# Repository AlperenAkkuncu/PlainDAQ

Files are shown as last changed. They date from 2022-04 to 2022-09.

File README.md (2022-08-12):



# PlainDAQ

PlainDAQ is a module that turns your Raspberry Pi Pico into a simple, precision 4-channel oscilloscope and a single channel function generator. Optionally it can also include a Wi-Fi module to add wireless capability to Raspberry Pi Pico modules.

To put it other words, PlainDAQ is a simple, useful tool to add basic precision analog functionality to your Raspberry Pi Pico board. It has a precision, low-noise, low-drift 12-bit 500kSPS/s ADC, sampling 4-channels and supporting 3 ranges (±1V, ±2V, ±4V). It also has a 10-bit DAC which helps create analog outputs and waveforms and it has a single range of ±4V.

Short List of features:

Analog Inputs:
• 4 Channels (multiplexed)  
• 12-bit resolution, 72dB SNR (11.6 ENOB,4000:1 dynamic range)  
• 500 kS/s sampling rate. 
• ±1V, ±2V, ±4V bipolar ranges.  

Analog Output:  
• 10-bit resolution.  
• 50 kS/s sampling rate.  
• ±4V bipolar range.  

Voltage Reference:
• 2.5V, 20ppm/°C (Typical) Drift  
• Calibrate to 0.05%, Stored in as ROM as calibration data. 

Bipolar Voltage Supply: 
• ±5V power output.   
• ±100mA current rating.    

ESP-WROOM-02D AT-Command Module:
• Simple UART interface to Raspberry Pico
• Wi-Fi connectivity    
• Shipped with ESP AT firmware 

# Here are some nice pictures of PlainDAQ
PlainDAQ_new_2
PlainDAQ_new_4

### Filter! More on that later
Filters

### The kit!
PlainDAQ_filters

## PlainDAQ Connections
plaindaq-board-layout-1

## PlainDAQ Components
plaindaq-board-layout-2

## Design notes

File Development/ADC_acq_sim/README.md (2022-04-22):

In PlainDAQ project I used PIO to interface with the ADC on board. 
"ADC_acq_sim" project simualted the ADC with PIO and acquires the data with PIO.

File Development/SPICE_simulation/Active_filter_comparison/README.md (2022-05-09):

Building a reconstruction filter for DAC output, so that I can generate nice looking sinewaves.
Here are the results:
The circuits I am comparing look like this:


The results are shown below:

As you can see MFB filter performs much better in the stop band

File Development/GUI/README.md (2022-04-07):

𝐒𝐭𝐫𝐞𝐬𝐬 𝐓𝐞𝐬𝐭
sinewave_stress_test

𝐂𝐮𝐫𝐬𝐨𝐫 𝐓𝐞𝐬𝐭

cursor_test

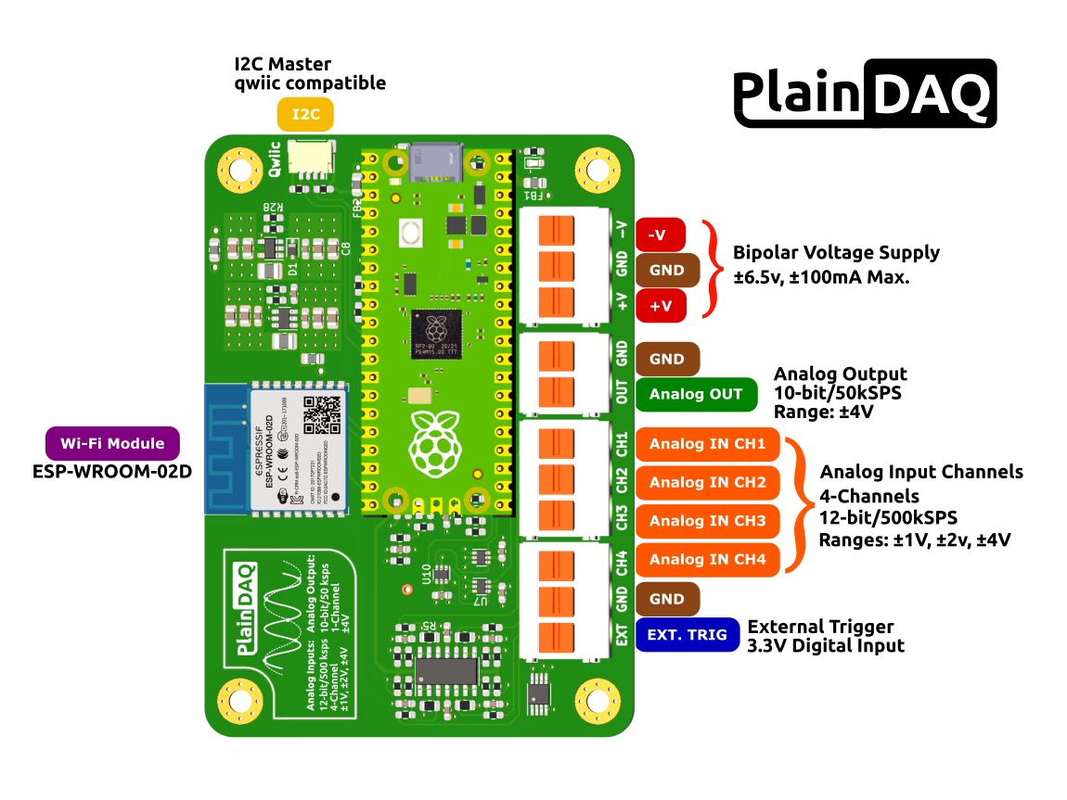
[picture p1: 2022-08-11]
pics/plaindaq-board-layout-1.png

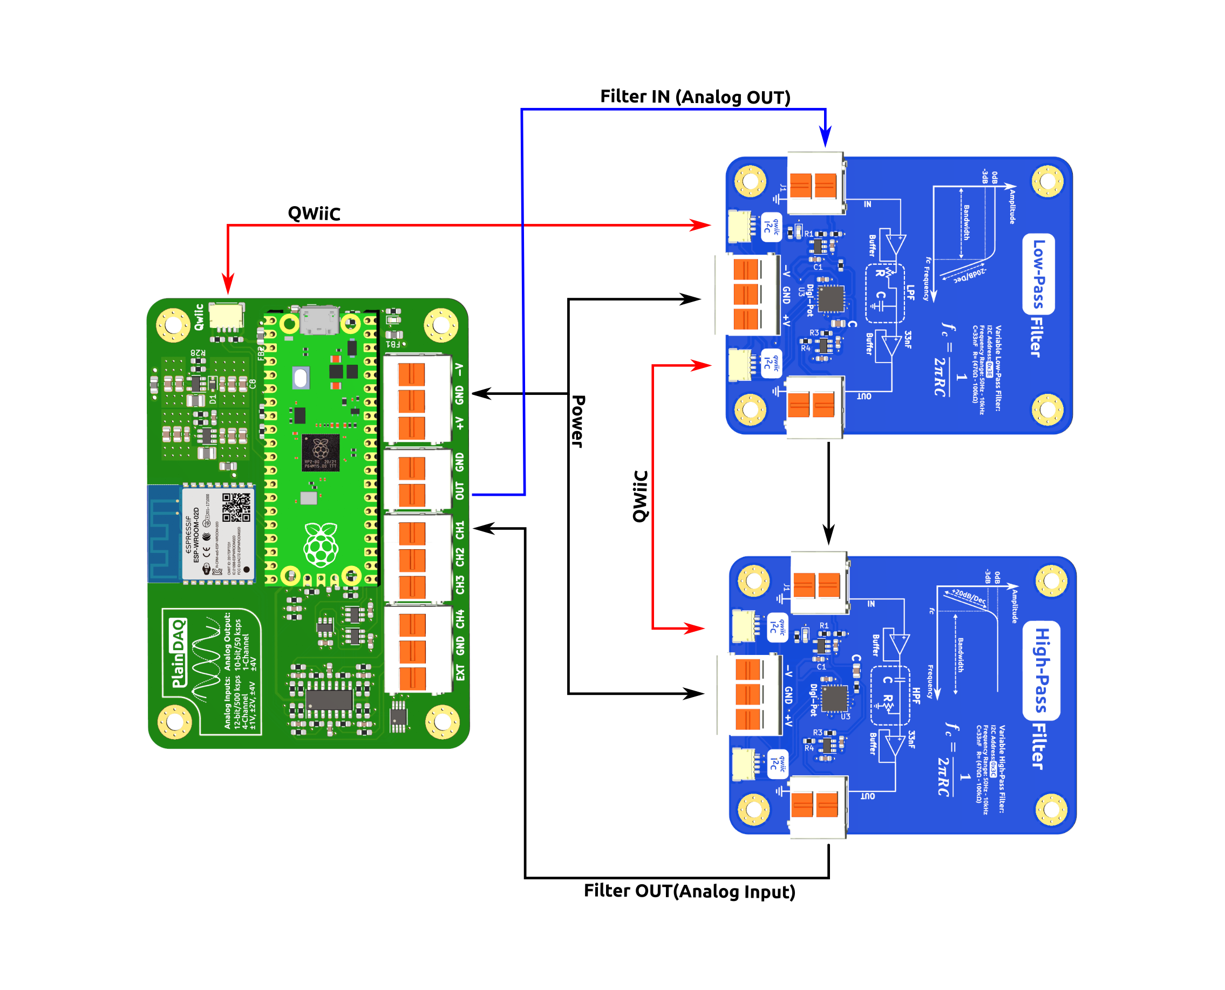
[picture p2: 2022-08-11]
pics/plaindaq-band-stop.png

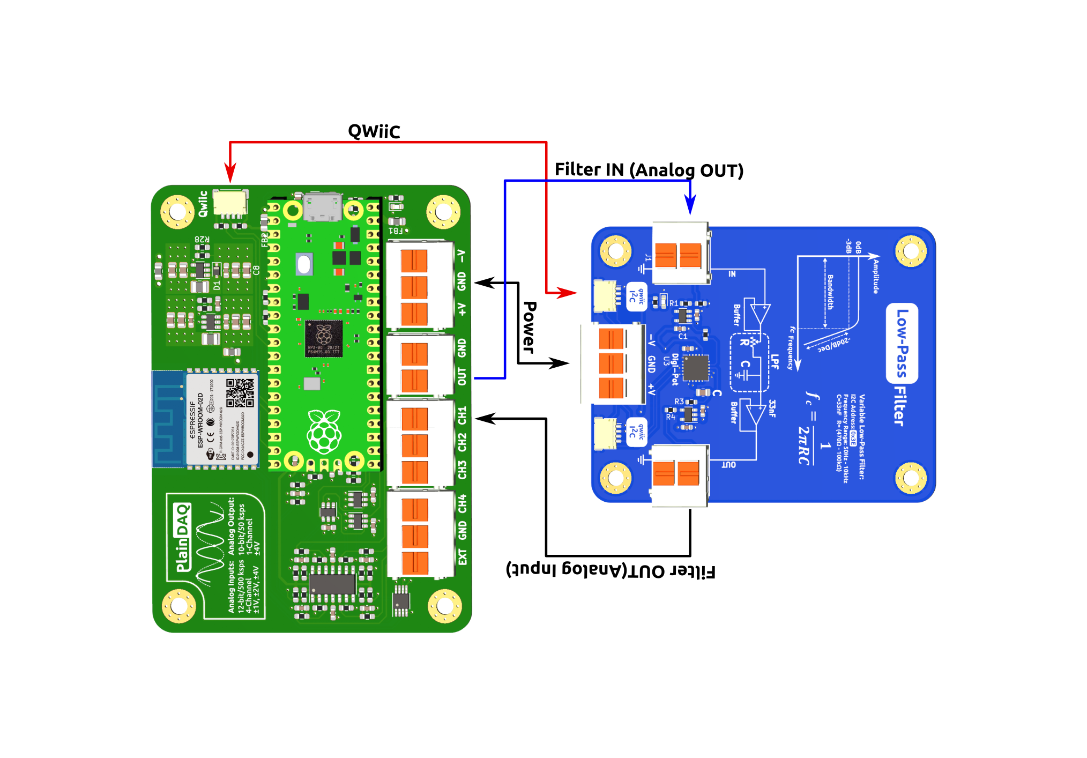
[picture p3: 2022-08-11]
pics/plaindaq-low-pass.png

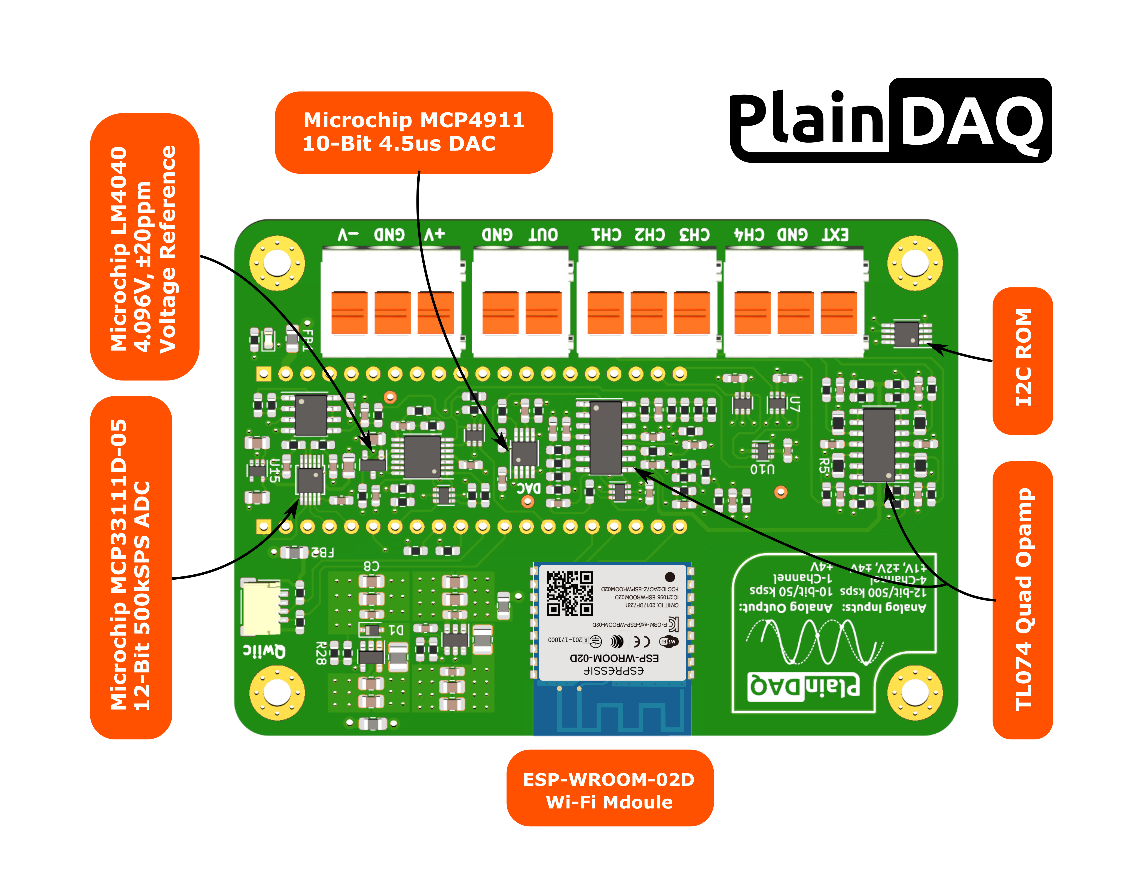
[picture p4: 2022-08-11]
pics/plaindaq-board-layout-2.png

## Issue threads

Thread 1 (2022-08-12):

Wi-Fi Module (to remove or not to remove)

AlperenAkkuncu, 2022-08-12:
Someone suggested me to remove the Wi-Fi module because one can buy a raspberry pico W and have the Wi-Fi capability, so there is no point having it in the board.

I've been thinking about removing it and adding a new feature.

What do you guys think?

avehbiaslanturk, 2022-08-12:
Yeah it might be good idea but first you should be sure that if it will be able to meet your needs in this project.

Derfboy, 2022-08-13:
Would definitely recommend removing it but also maybe having a fork that keeps it in for those of us who can't get our hands on the new Pico W.

Blaster1920, 2022-08-15:
I would remove it too.

Closed 2022-08-22.

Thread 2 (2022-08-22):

PlainDAQ new feature reccomendation.

AlperenAkkuncu, 2022-08-22:
Hello everyone,
I decided to remove the wi-fi module as Raspberry pico W is out and I am considering adding a new feature.

**What do you think I should add?**

These are some of the things I thought of adding:

- Storage (RAM, SDCard etc.)
- Variable power supply

What are your suggestions?

shanemmattner, 2022-08-24:
The [Espotek Labador](https://espotek.com/labrador/) seems to be doing similar functions as `PlainDAQ`, albeit with a simpler analog front end and no connectivity.  Take a look and see if there's anything worth stealing.

**Ideas/Comments**
- Use `ESP32` instead of `RPi Pico W`
  - Advantages:  Faster, FPU, lower sleep current, longer history in market, cheaper, smaller, professional quality chip, availability
- `SD card` is a good idea for longer term captures
- `Extra RAM` is probably useful, is it necessary yet?
- Couldn't the `DAC` act as a variable power supply?
- `Logic analyzer/generator`
- `Battery` circuit
- `Larger input range`
  - How high of voltage is practical (10v/20v/...)?
- `Circuit protection` like fuses and TVS diodes

AlperenAkkuncu, 2022-08-24:
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

Thank you for your contribution

I'll consider all of them, but I don't want to add too much functionality because I want to make something affordable and easy to manufacture. SDCard is definitely great as it's cheap to just add a connector, that's almost no brainer.

Extra RAM is quite good actually, but it's actually a bit expensive, but it might worth it.

It's kind of easy to add variable supply if things works according to my plan. I am planing to build a simple PWM DAC to create a variable supply, we'll see what I can do :)

I'll consider all of them for the future updates, thanks a lot.

Feedbacks like this motivates me.

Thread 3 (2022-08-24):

U3A -OUT supposed to connect to R14?

shanemmattner, 2022-08-24:
Should the `-OUT` be connected to R14 here?
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

AlperenAkkuncu, 2022-08-24:
Sorry for my late response @shanemmattner I am still getting used to github :)
Yes you are correct.
I will remove this schematic as it's not relevant right. I will upload the new version of the schematic files, once I launch the project on crowduspply.

In fact, I will share the whole KiCAD project :D

shanemmattner, 2022-08-24:
No problem, <24 hours response time on Github is lightning quick haha.

I look forward to seeing the full KiCAD project.  A brief explanation of the circuits (ie U2A and U3A) or links to documents you used to make the circuits would be great as well.

AlperenAkkuncu, 2022-08-24:
Thanks for the kind words :)
@shanemmattner are you asking the function of the FDA?

shanemmattner, 2022-08-24:
Yes, the FDA is a good example.  I didn't know the name of the circuit so I did not understand how it works.  I've created [this issue](https://github.com/AlperenAkkuncu/PlainDAQ/issues/4) for adding circuit theory documentation.  Let me know if I can help

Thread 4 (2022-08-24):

Add circuit theory documentation

shanemmattner, 2022-08-24:
It would be great to have a brief description of the circuits and perhaps some links to documentation explaining how the circuits work. I can help create the documents if you'd like

For example, in the picture below of U2A/U2B:

- `U2A` is a [voltage buffer](https://ultimateelectronicsbook.com/op-amp-voltage-buffer/)
- R5/R8 divide the input by 2
- `U2B` is a [summing differential amplifier](https://masteringelectronicsdesign.com/a-summing-and-differential-amplifier-with-one-op-amp/)
  - Is this correct?  Perhaps the equation for this circuit would be helpful
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

Then U3A circuits:
- `U3A` is a [fully-differential amplifier](https://www.ti.com/lit/an/sloa054e/sloa054e.pdf?ts=1661319105267)
- Output of `U3A` fed through [RC filters](https://www.electronics-tutorials.ws/filter/filter_2.html) (ie `R6`/`C4`, `R11`/`C7`) with cut-off freq ~`59Mhz`
  - Why 59Mhz?
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

AlperenAkkuncu, 2022-08-24:
> It would be great to have a brief description of the circuits and perhaps some links to documentation explaining how the circuits work. I can help create the documents if you'd like

That's a good idea. I was thinking about making videos, but I am not too sure how difficult it would be. Documenting stuff on github is a lot more efficient for me actually.

> * `U2A` is a [voltage buffer](https://ultimateelectronicsbook.com/op-amp-voltage-buffer/)
> * R5/R8 divide the input by 2

That's correct

> * `U2B` is a [summing differential amplifier](https://masteringelectronicsdesign.com/a-summing-and-differential-amplifier-with-one-op-amp/)

That's not correct, it's just a non-inverting opamp, if you follow the nets analog mux (U5) connects the resistor networks to achieve different gains.

> Output of `U3A` fed through [RC filters](https://www.electronics-tutorials.ws/filter/filter_2.html) (ie `R6`/`C4`, `R11`/`C7`) with cut-off freq ~`59Mhz`
> * Why 59Mhz?

It's kind of random, usually you need to use the lowest BW that you can work with to drive the ADC. Driving ADCs are quite difficult because it needs a lot of bandwidth. Determining exact values are quite difficult it's just requires quite a lot of trial and errors.

shanemmattner, 2022-08-25:
Making videos can be as involved as you'd like to make them.  I just uploaded some [new videos](https://youtube.com/playlist?list=PLkch9g9DEE0KpS7v0Ob3cLrQlZsCPJ6PP) on using SKiDL to make an ESP32 data logger (analog front end based on your project, thank you!).  You'll see they are pretty basic and just me talking over a screen.

AlperenAkkuncu, 2022-08-25:
> Making videos can be as involved as you'd like to make them. I just uploaded some [new videos](https://youtube.com/playlist?list=PLkch9g9DEE0KpS7v0Ob3cLrQlZsCPJ6PP) on using SKiDL to make an ESP32 data logger (analog front end based on your project, thank you!). You'll see they are pretty basic and just me talking over a screen.

Once I get an OK mic I can make it.
Great stuff by the way. :)

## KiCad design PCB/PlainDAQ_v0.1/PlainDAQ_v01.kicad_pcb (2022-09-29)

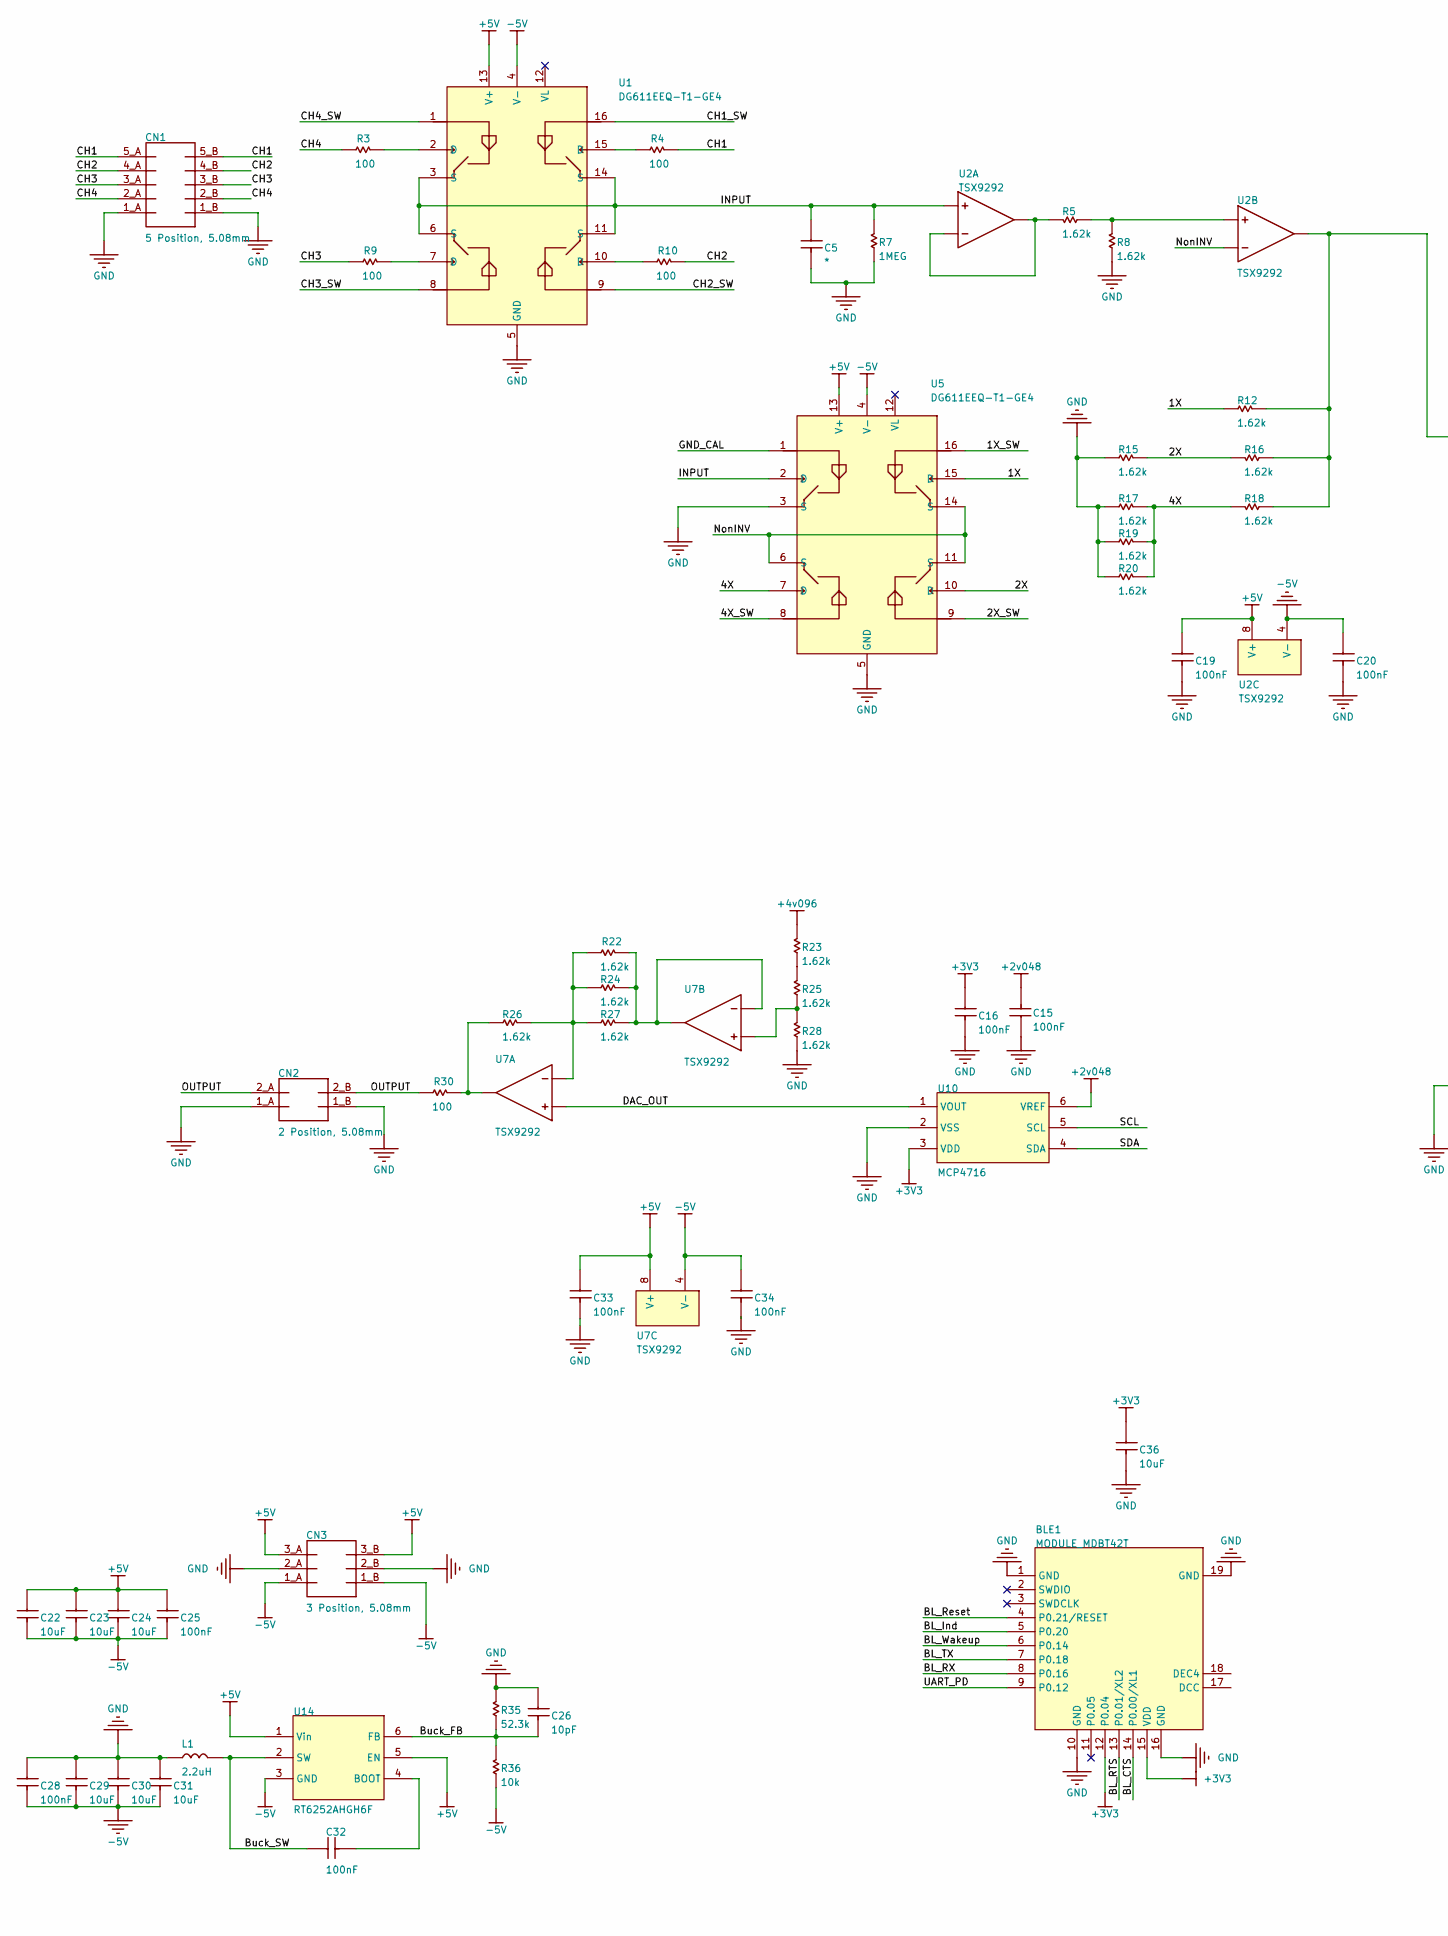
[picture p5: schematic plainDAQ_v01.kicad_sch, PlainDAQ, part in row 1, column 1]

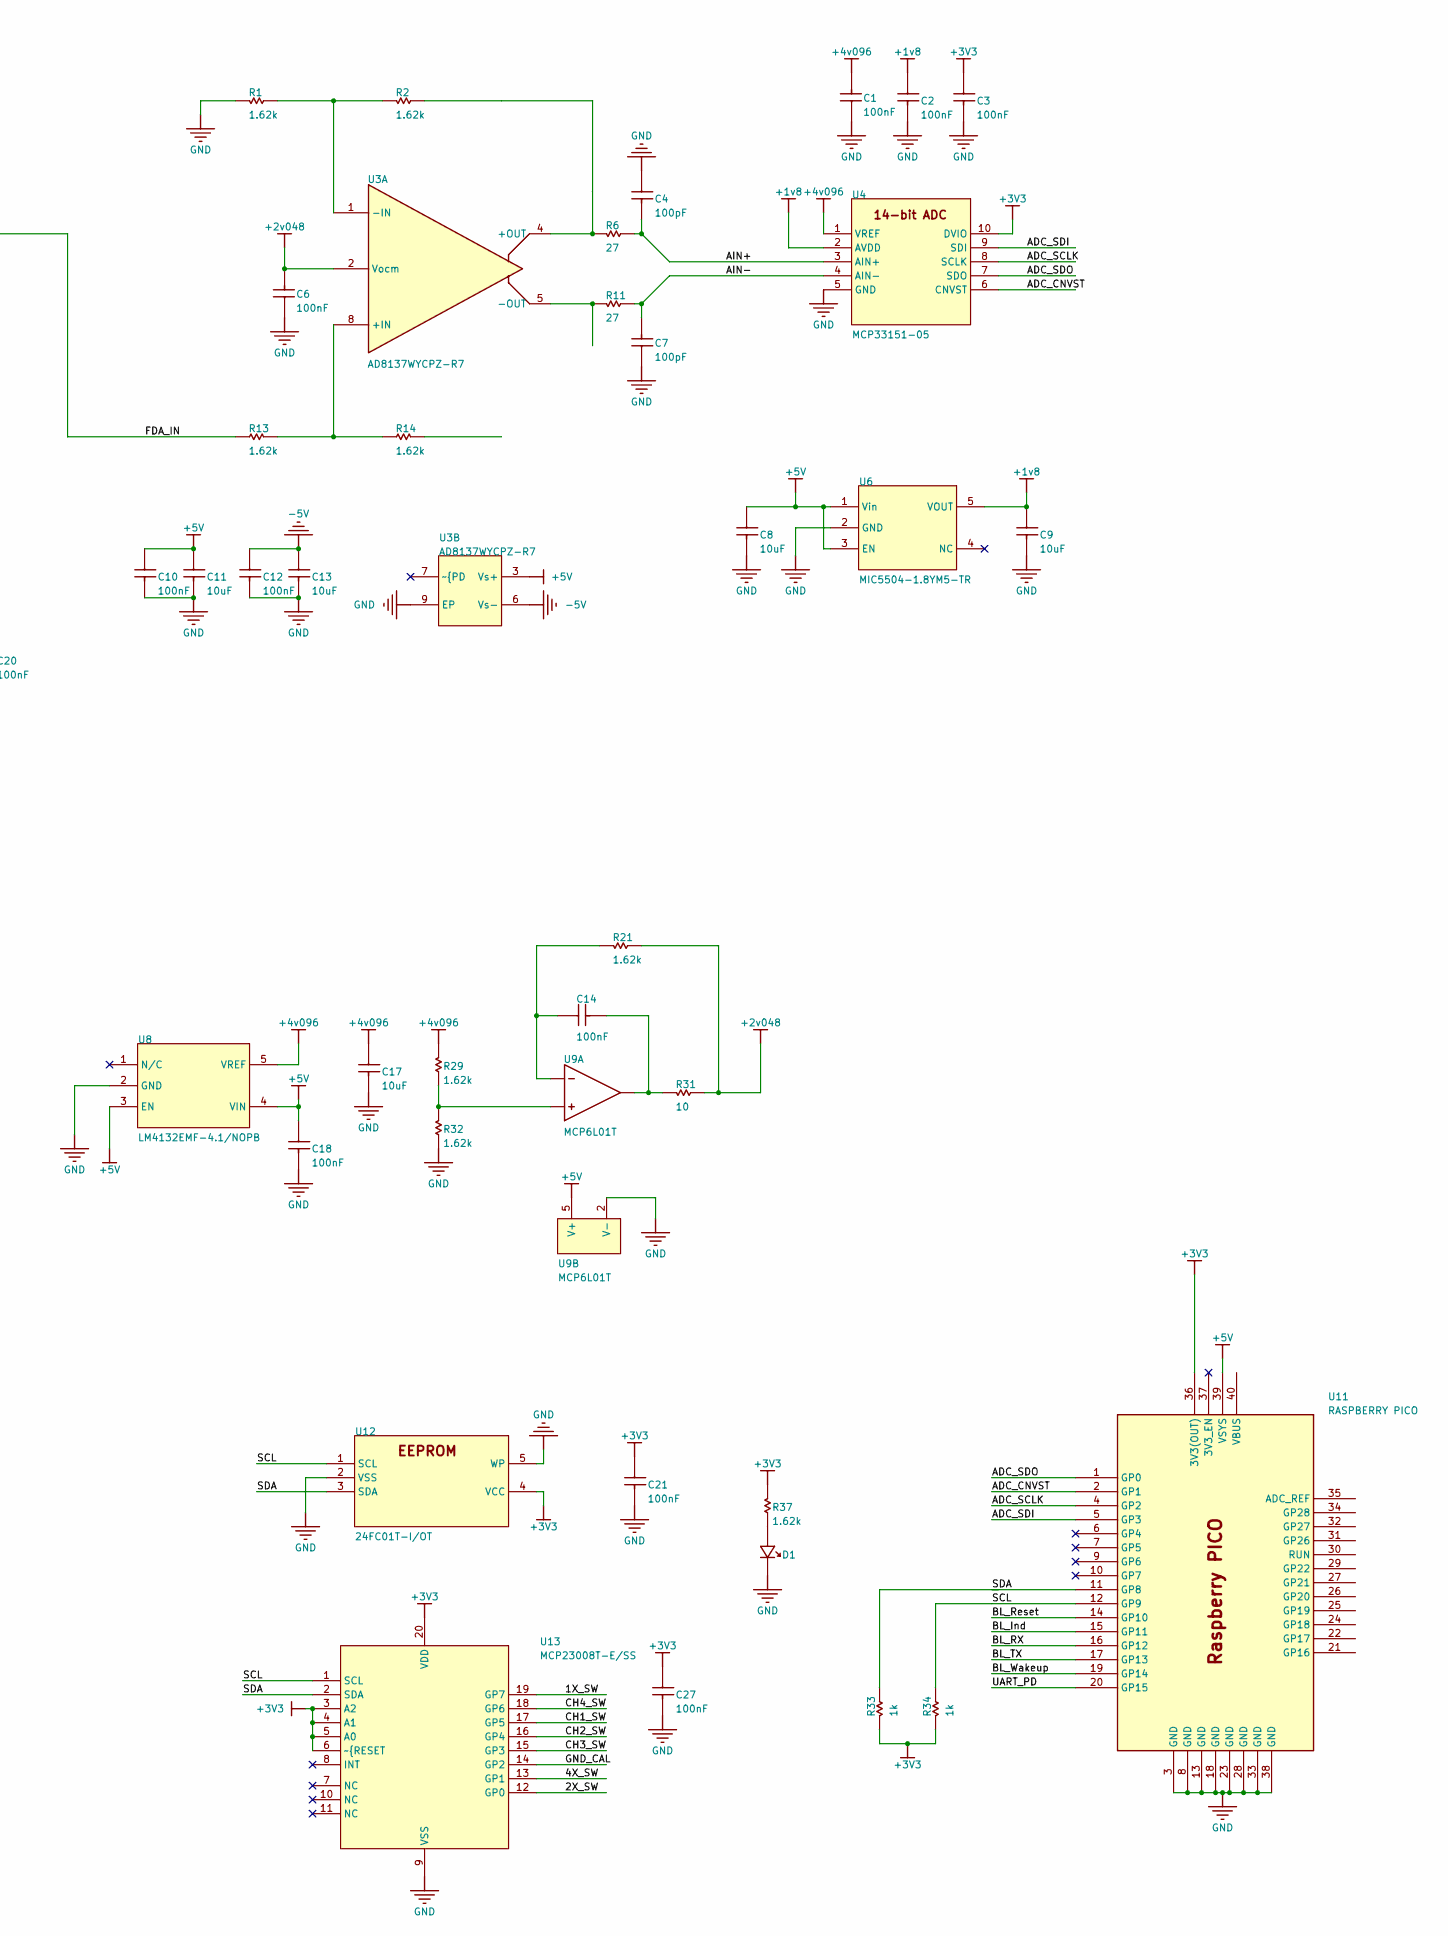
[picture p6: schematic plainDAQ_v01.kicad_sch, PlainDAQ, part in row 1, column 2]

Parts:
BLE1: MODULE_MDBT42T; PCB_MDBT42T_7.2X11.2
C1, C2, C3, C6, C10, C12, C14, C15, C16, C18, C19, C20, C21, C25, C27, C28, C32, C33, C34: 100nF; CAP-0603; TOLERANCE *
C4, C7: 100pF; CAP-0603; TOLERANCE *
C5: *; CAP-0603; TOLERANCE 10pF
C8, C9, C11, C13, C17, C22, C23, C24, C29, C30, C31, C36: 10uF; CAP-0805; TOLERANCE *
C26: 10pF; CAP-0603; TOLERANCE *
CN1: 5 Position, 5.08mm; CUI_TBL004-508-05BE-2GY; MANUFACTURER P/N TBL004V-508-05BE-2GY
CN2: 2 Position, 5.08mm; CUI_TBL004-508-02BE-2GY; MANUFACTURER P/N TBL004V-508-02BE-2GY
CN3: 3 Position, 5.08mm; CUI_TBL004-508-03BE-2GY; MANUFACTURER P/N TBL004V-508-03BE-2GY
D1: 150060SS75000; LED-0603
L1: 2.2uH; IND-0806
R1, R2, R5, R8, R12, R13, R14, R15, R16, R17, R18, R19, R20, R21, R22, R23, R24, R25, R26, R27, R28, R29, R32, R37: 1.62k; Res-0603; TOLERANCE *
R3, R4, R9, R10, R30: 100; Res-0603; TOLERANCE *
R6, R11: 27; Res-0603; TOLERANCE *
R7: 1MEG; Res-0603; TOLERANCE *
R31: 10; Res-0603; TOLERANCE *
R33, R34: 1k; Res-0603; TOLERANCE *
R35: 52.3k; Res-0603; TOLERANCE *
R36: 10k; Res-0603; TOLERANCE *
U1, U5: DG611EEQ-T1-GE4; TSOP65P640X110-16N
U2, U7: TSX9292; TSOP6-8 4x4 (NO PAD); MANUFACTURER P/N TSX9292IST
U3: AD8137WYCPZ-R7; SON-8 3.0X3.0, 2.00x1.49 PAD
U4: MCP33151-05; TSSOP50P490X110-10N; MANUFACTURER P/N MCP33151-05-E/MS
U6: MIC5504-1.8YM5-TR; SOT95P280X100-5N
U8: LM4132EMF-4.1/NOPB; SOT95P280X100-5N
U9: MCP6L01T; SOT65P210X110-5N; MANUFACTURER P/N MCP6L01T-E/LT
U10: MCP4716; SOT95P275X110-6N; MANUFACTURER P/N MCP4716A2T-E/CH
U11: RASPBERRY PICO; Raspberry_PICO
U12: 24FC01T-I/OT; SOT65P210X110-5N
U13: MCP23008T-E/SS; SOP65P780X200-20N
U14: RT6252AHGH6F; SOTFL50P160X60-6N

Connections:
1X: R12.2, U5.15 (D)
1X_SW: U5.16, U13.19 (GP7)
2X: R15.1, R16.1, U5.10 (D)
2X_SW: U5.9, U13.12 (GP0)
4X: R17.1, R18.1, R19.1, R20.1, U5.7 (D)
4X_SW: U5.8, U13.13 (GP1)
+1v8: C2.2, C9.2, U4.2 (AVDD), U6.5 (VOUT)
+2v048: C6.1, C15.1, R21.2, R31.2, U3.2 (Vocm), U10.6 (VREF)
+3V3: BLE1.12 (P0.04), BLE1.15 (VDD), C3.2, C16.2, C21.2, C27.2, C36.2, R33.2, R34.2, R37.1, U4.10 (DVIO), U10.3 (VDD), U11.36 (3V3(OUT)), U12.4 (VCC), U13.3 (A2), U13.4 (A1), U13.5 (A0), U13.6 (~{RESET), U13.20 (VDD); also elsewhere on the board
+4v096: C1.1, C17.2, R23.1, R29.1, U4.1 (VREF), U8.5 (VREF)
+5V: C8.2, C10.2, C11.2, C18.2, C19.2, C22.2, C23.2, C24.2, C25.2, C33.2, CN3.3_A, CN3.3_B, U1.13 (V+), U2.8 (V+), U3.3 (Vs+), U5.13 (V+), U6.1 (Vin), U6.3 (EN), U7.8 (V+), U8.3 (EN), U8.4 (VIN), U9.5 (V+), U11.39 (VSYS), U14.1 (Vin), U14.5 (EN)
-5V: C12.2, C13.2, C20.2, C22.1, C23.1, C24.1, C25.1, C28.1, C29.1, C30.1, C31.1, C34.2, CN3.1_A, CN3.1_B, R36.1, U1.4 (V-), U2.4 (V-), U3.6 (Vs-), U5.4 (V-), U7.4 (V-), U14.3 (GND)
ADC_CNVST: U4.6 (CNVST), U11.2 (GP1)
ADC_SCLK: U4.8 (SCLK), U11.4 (GP2)
ADC_SDI: U4.9 (SDI), U11.5 (GP3)
ADC_SDO: U4.7 (SDO), U11.1 (GP0)
AIN+: C4.1, R6.1, U4.3 (AIN+)
AIN-: C7.1, R11.1, U4.4 (AIN-)
BL_Ind: BLE1.5 (P0.20), U11.15 (GP11); also elsewhere on the board
BL_RX: BLE1.8 (P0.16), U11.16 (GP12); also elsewhere on the board
BL_Reset: BLE1.4 (P0.21/RESET), U11.14 (GP10); also elsewhere on the board
BL_TX: BLE1.7 (P0.18), U11.17 (GP13); also elsewhere on the board
BL_Wakeup: BLE1.6 (P0.14), U11.19 (GP14); also elsewhere on the board
Buck_FB: C26.1, R35.1, R36.2, U14.6 (FB)
Buck_SW: C32.2, L1.2, U14.2 (SW)
CH1: CN1.5_A, CN1.5_B, R4.1
CH1_SW: U1.16, U13.17 (GP5)
CH2: CN1.4_A, CN1.4_B, R10.1
CH2_SW: U1.9, U13.16 (GP4)
CH3: CN1.3_A, CN1.3_B, R9.2
CH3_SW: U1.8, U13.15 (GP3)
CH4: CN1.2_A (3), CN1.2_B, R3.2
CH4_SW: U1.1, U13.18 (GP6)
DAC_OUT: U7.3 (+INA), U10.1 (VOUT)
FDA_IN: R12.1, R13.2, R16.2, R18.2, U2.7 (OUTB)
GND: BLE1.1 (GND), BLE1.10 (GND), BLE1.16 (GND), BLE1.19 (GND), C1.2, C2.1, C3.1, C4.2, C5.1, C6.2, C7.2, C8.1, C9.1, C10.1, C11.1, C12.1, C13.1, C15.2, C16.1, C17.1, C18.1, C19.1, C20.1, C21.1, C26.2, C27.1, C28.2, C29.2, C30.2, C31.2, C33.1, C34.1, C36.1, CN1.1_A, CN1.1_B, CN2.1_A, CN2.1_B, CN3.2_A (3), CN3.2_B, D1.1, L1.1, R1.2, R7.2, R8.2, R15.2, R17.2, R19.2, R20.2, R28.2, R32.2, R35.2, U1.5 (GND), U3.9 (EP), U4.5 (GND), U5.3 (S), U5.5 (GND), U6.2 (GND), U8.2 (GND), U9.2 (V-), U10.2 (VSS), U11.3 (GND), U11.8 (GND), U11.13 (GND), U11.18 (GND), U11.23 (GND), U11.28 (GND), U11.33 (GND), U11.38 (GND), U12.2 (VSS), U12.5 (WP), U13.9 (VSS); also elsewhere on the board
GND_CAL: U5.1, U13.14 (GP2)
INPUT: C5.2, R7.1, U1.3 (S), U1.6 (S), U1.11 (S), U1.14 (S), U2.3 (+INA), U5.2 (D)
NetC14_1: C14.1, R31.1, U9.1 (OUT)
NetC14_2: C14.2, R21.1, U9.4 (-IN)
NetC32_1: C32.1, U14.4 (BOOT)
NetD1_2: D1.2, R37.2
NetR1_1: R1.1, R2.2, U3.1 (-IN)
NetR2_1: R2.1, R6.2, U3.4 (+OUT)
NetR3_1: R3.1, U1.2 (D)
NetR4_2: R4.2, U1.15 (D)
NetR5_1: R5.1, R8.1, U2.5 (+INB)
NetR5_2: R5.2, U2.1 (OUTA), U2.2 (-INA)
NetR9_1: R9.1, U1.7 (D)
NetR10_2: R10.2, U1.10 (D)
NetR13_1: R13.1, R14.2, U3.8 (+IN)
NetR22_1: R22.1, R24.1, R27.1, U7.6 (-INB), U7.7 (OUTB)
NetR22_2: R22.2, R24.2, R26.1, R27.2, U7.2 (-INA)
NetR23_2: R23.2, R25.1
NetR25_2: R25.2, R28.1, U7.5 (+INB)
NetR26_2: R26.2, R30.1, U7.1 (OUTA)
NetR29_2: R29.2, R32.1, U9.3 (+IN)
NonINV: U2.6 (-INB), U5.6 (S), U5.11 (S), U5.14 (S)
OUTPUT: CN2.2_A (3), CN2.2_B, R30.2
SCL: R34.1, U10.5 (SCL), U11.12 (GP9), U12.1 (SCL), U13.1 (SCL)
SDA: R33.1, U10.4 (SDA), U11.11 (GP8), U12.3 (SDA), U13.2 (SDA)
UART_PD: BLE1.9 (P0.12), U11.20 (GP15); also elsewhere on the board

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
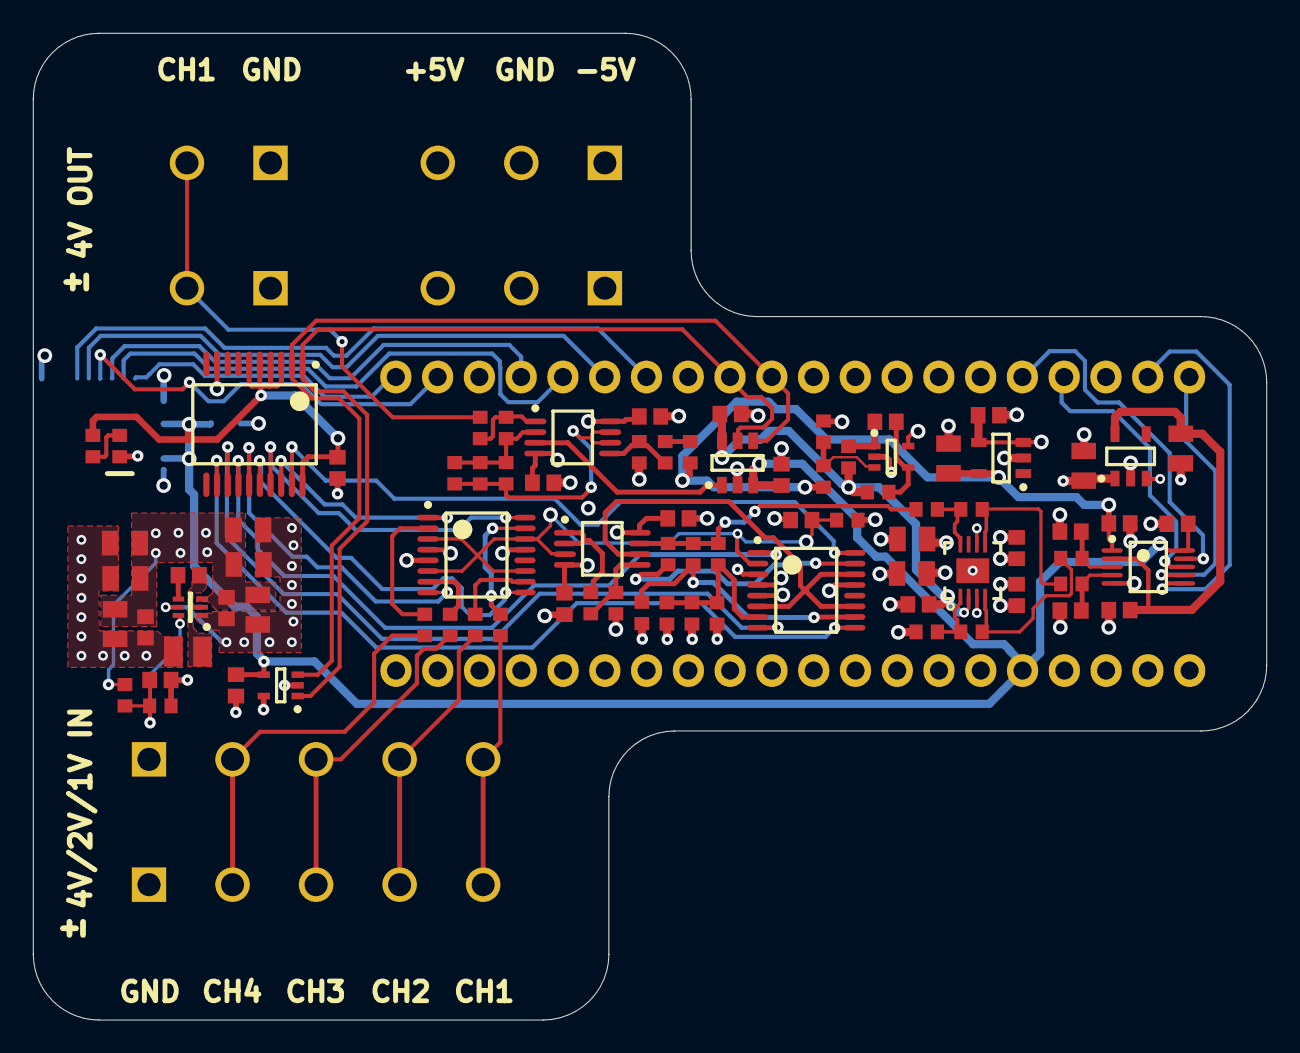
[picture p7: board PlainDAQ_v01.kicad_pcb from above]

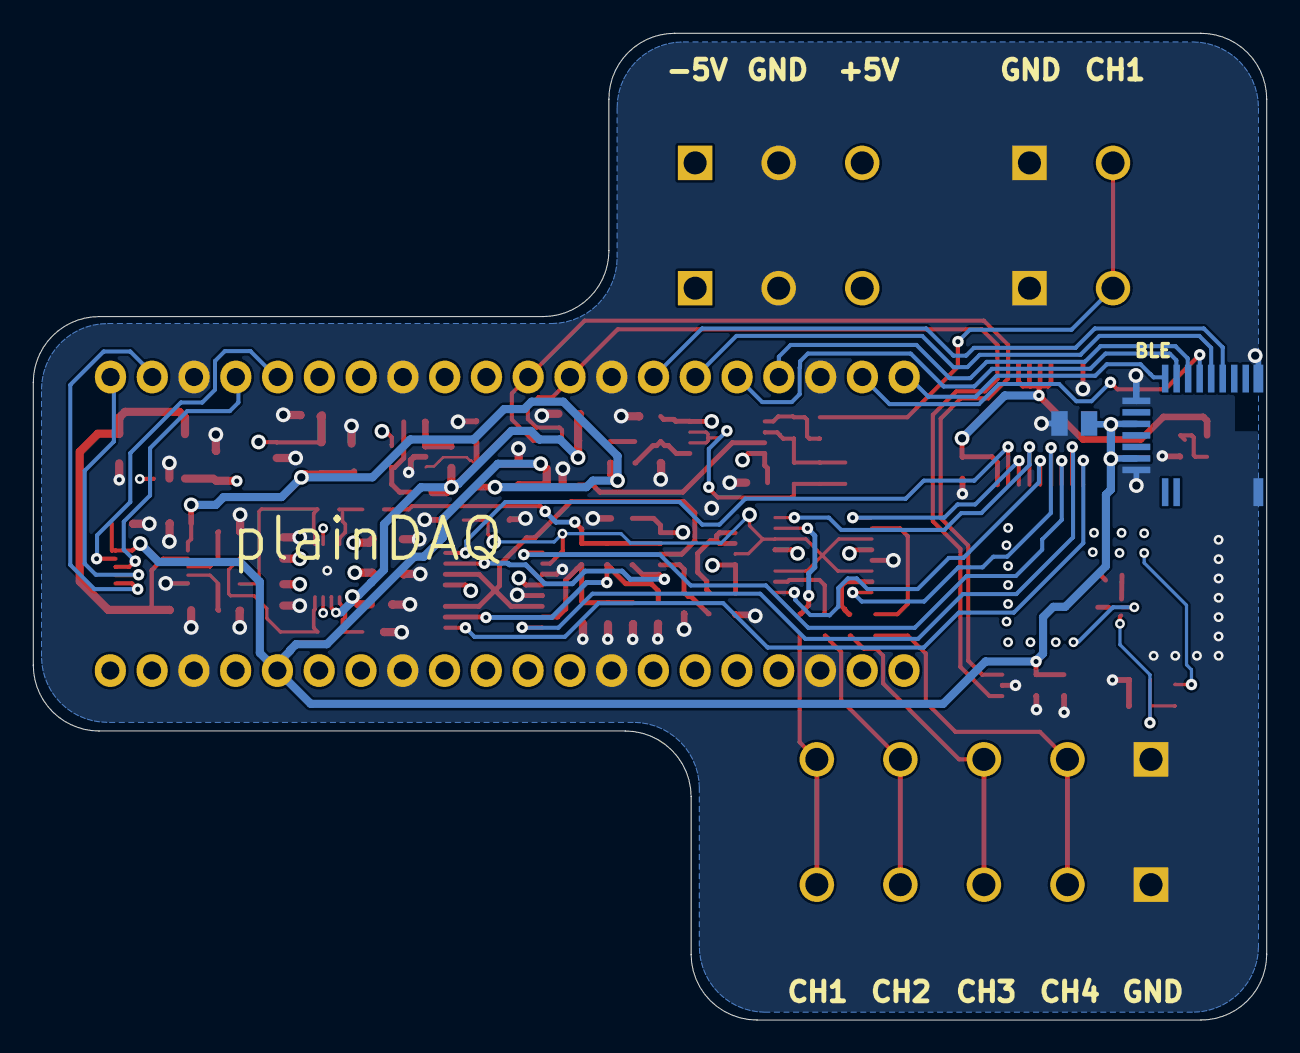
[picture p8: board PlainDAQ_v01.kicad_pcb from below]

Board: 4 copper layers, 75.0 x 60.0 mm, 90 parts (2 on the bottom side), 63 nets.

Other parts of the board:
BLE: MODULE_MDBT42T; PCB_MDBT42T_7.2X11.2

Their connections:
+3V3: BLE.12, BLE.15; also elsewhere on the board
BL_Ind: BLE.5; also elsewhere on the board
BL_RX: BLE.8; also elsewhere on the board
BL_Reset: BLE.4; also elsewhere on the board
BL_TX: BLE.7; also elsewhere on the board
BL_Wakeup: BLE.6; also elsewhere on the board
GND: BLE.1, BLE.10, BLE.16, BLE.19; also elsewhere on the board
UART_PD: BLE.9; also elsewhere on the board

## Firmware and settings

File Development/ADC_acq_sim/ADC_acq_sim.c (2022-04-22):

/**
 * Copyright (c) 2020 Raspberry Pi (Trading) Ltd.
 *
 * SPDX-License-Identifier: BSD-3-Clause
 */

// Output PWM signals on pins 0 and 1

#define ADC_SDO 0
#define ADC_CNVST 1
#define ADC_SCLK 2
#define ADC_SDI 3
#define ADC_SDO_SIM 4

#define CLK_GEN_SM 0
#define GET_SAMPLE_SM 1
#define GEN_DATA_SM 2

#define IO_EXPANDER_ADDR 0x27
#define IODIR 0x00
#define IOPOL 0x01
#define OLAT 0x0A

#define CLK_FREQ 125000000
#define PWM_FREQ 500000

#include <stdio.h>
#include <math.h>
#include "pico/stdlib.h"
#include "hardware/pwm.h"
#include "hardware/clocks.h"
#include "hardware/pio.h"
#include "hardware/i2c.h"
#include "hardware/irq.h"
#include "ADC_acq_sim.pio.h"
#include "pico/binary_info.h"

uint16_t sample = 0;
uint32_t sample_tx_buff[4096], sample_rx_buff[4096];


void pio_sample_irq(){
    static uint32_t i = 0;
    irq_clear(PIO0_IRQ_0);
    if(i>4095){
        i = 0;
        sample_rx_buff[i] = pio_sm_get(pio0, GET_SAMPLE_SM);
        i++;
    }
    else{
        sample_rx_buff[i] = pio_sm_get(pio0, GET_SAMPLE_SM);
        i++;
    }
}

/*******************************************************************************
 * Function Declarations
 */
int reg_write(i2c_inst_t *i2c, 
                const uint addr, 
                const uint8_t reg, 
                uint8_t *buf,
                const uint8_t nbytes);

int reg_read(   i2c_inst_t *i2c,
                const uint addr,
                const uint8_t reg,
                uint8_t *buf,
                const uint8_t nbytes);

/*******************************************************************************
 * Function Definitions
 */

// Write 1 byte to the specified register
int reg_write(  i2c_inst_t *i2c, 
                const uint addr, 
                const uint8_t reg, 
                uint8_t *buf,
                const uint8_t nbytes) {

    int num_bytes_read = 0;
    uint8_t msg[nbytes + 1];

    // Check to make sure caller is sending 1 or more bytes
    if (nbytes < 1) {
        return 0;
    }

    // Append register address to front of data packet
    msg[0] = reg;
    for (int i = 0; i < nbytes; i++) {
        msg[i + 1] = buf[i];
    }

    // Write data to register(s) over I2C
    i2c_write_blocking(i2c, addr, msg, (nbytes + 1), false);

    return num_bytes_read;
}

// Read byte(s) from specified register. If nbytes > 1, read from consecutive
// registers.
int reg_read(  i2c_inst_t *i2c,
                const uint addr,
                const uint8_t reg,
                uint8_t *buf,
                const uint8_t nbytes) {

    int num_bytes_read = 0;

    // Check to make sure caller is asking for 1 or more bytes
    if (nbytes < 1) {
        return 0;
    }

    // Read data from register(s) over I2C
    i2c_write_blocking(i2c, addr, &reg, 1, true);
    num_bytes_read = i2c_read_blocking(i2c, addr, buf, nbytes, false);

    return num_bytes_read;
}

// I2C reserves some addresses for special purposes. We exclude these from the scan.
// These are any addresses of the form 000 0xxx or 111 1xxx
bool reserved_addr(uint8_t addr) {
    return (addr & 0x78) == 0 || (addr & 0x78) == 0x78;
}

void init_I2C(){
    i2c_init(i2c_default, 100 * 1000);
    gpio_set_function(8, GPIO_FUNC_I2C);
    gpio_set_function(9, GPIO_FUNC_I2C);
    gpio_pull_up(8);
    gpio_pull_up(9);
    // Make the I2C pins available to picotool
    bi_decl(bi_2pins_with_func(8, 9, GPIO_FUNC_I2C));
}

void set_channel_and_range(){
    uint8_t data;
    
    //setting channel one and range 1X
    //don't have much time to write a generic code...
    data = 0x5F;
    reg_write(i2c_default, IO_EXPANDER_ADDR, OLAT, &data,1);
    data = 0x00;
    reg_write(i2c_default, IO_EXPANDER_ADDR, IODIR, &data,1);
}

int main() {

       // Enable UART so we can print status output
    //stdio_init_all();

    /// \tag::ADC_SDI[]
    gpio_init(ADC_SDI);
    gpio_set_dir(ADC_SDI, GPIO_OUT);
    gpio_put(ADC_SDI, 1);
    /// \end::ADC_SDI[]
    
    /// \tag::i2c[]
    init_I2C();
    set_channel_and_range();
    /// \end::i2c[]

    /// \tag::pio[]
    // Choose PIO instance (0 or 1)
    PIO pio = pio0;
    PIO pio_1 = pio1;
    // Get first free state machine in PIO 0
    //uint sm_clk = pio_claim_unused_sm(pio, true);
    //uint sm_gen = pio_claim_unused_sm(pio_1, true);
    //uint sm_get_samples = pio_claim_unused_sm(pio, true);

    // Add PIO program to PIO instruction memory. SDK will find location and
    // return with the memory offset of the program.
    uint offset_clk = pio_add_program(pio0, &ADC_SCLK_gen_program);
    uint offset_gen = pio_add_program(pio0, &ADC_gen_sample_program);
    uint offset_get_sample = pio_add_program(pio0, &ADC_get_sample_program);

    // Initialize the program using the helper function in our .pio file
    ADC_SCLK_gen_init(pio0, CLK_GEN_SM, offset_clk, ADC_SCLK, 1);
    ADC_get_sample_init(pio0, GET_SAMPLE_SM, offset_get_sample,ADC_SDO_SIM);
    ADC_gen_sample_init(pio0, GEN_DATA_SM, offset_gen, ADC_SDO, 1);
    

    // Start running our PIO program in the state machine
    pio_sm_set_enabled(pio0, CLK_GEN_SM, true);
    pio_sm_set_enabled(pio0, GEN_DATA_SM, true);
    

    pio_set_irq0_source_enabled(pio0, pis_sm1_rx_fifo_not_empty, true);
    irq_set_exclusive_handler(PIO0_IRQ_0, &pio_sample_irq);
    irq_set_enabled(PIO0_IRQ_0, true);
    
    //pio0_hw->inte0 = PIO_IRQ0_INTE_SM0_BITS | PIO_IRQ0_INTE_SM1_BITS;
    /// \end::pio[]

    

    /// \tag::setup_pwm[]

    // Tell GPIO 0 and 1 they are allocated to the PWM
    //gpio_set_function(0, GPIO_FUNC_PWM);
    gpio_set_function(ADC_CNVST, GPIO_FUNC_PWM);

    // Find out which PWM slice is connected to GPIO 0 (it's slice 0)
    uint slice_num = pwm_gpio_to_slice_num(0);

    // Set period of 4 cycles (0 to 3 inclusive)
    pwm_set_wrap(slice_num, CLK_FREQ/PWM_FREQ );
    // Set initial B output high for three cycles before dropping
    // GPIO 1 is connected to PWM0B (datasheet page: 548)
    
    pwm_set_chan_level(slice_num, PWM_CHAN_B, 150);
    // Set the PWM running
    pwm_set_enabled(slice_num, true);
    /// \end::setup_pwm[]
    
    // Note we could also use pwm_set_gpio_level(gpio, x) which looks up the
    // correct slice and channel for a given GPIO.
    

    uint16_t i = sizeof(sample_tx_buff);
    
    for(i=0; i<( sizeof(sample_tx_buff)/4 ); i++){
        sample_tx_buff[i] = i;
        sample_rx_buff[i] = 0;
    }
        
    i = 0;

    pio_sm_set_enabled(pio0, GET_SAMPLE_SM, true);
    while(true){
                
        pio_sm_put_blocking(pio0, GEN_DATA_SM, (sample_tx_buff[i]<<20) );
        

        if( i >= (sizeof(sample_tx_buff)/4 - 1) )
            i = 0;
        else
            i++;

    }

}

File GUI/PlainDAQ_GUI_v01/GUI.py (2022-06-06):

import os
import logging
from plot import Plotter
import tkinter as tk
from tkinter import FLAT, SUNKEN, Frame, ttk
import sys
import ttkthemes
import signal
from PIL import ImageTk, Image



class GUI:
    def __init__(self):
        
        self.GUI_logger = logging.getLogger('example_logger')
        self.GUI_logger.warning('This is a warning')
        self.root = tk.Tk()
        self.root.geometry('800x650')
        self.root.protocol("WM_DELETE_WINDOW", self.on_closing)

        #setting theme
        theme_path = os.path.dirname(__file__) + "/Sun-Valley-ttk-theme-master/sun-valley.tcl"
        self.root.tk.call("source", theme_path)
        self.root.tk.call("set_theme", "light")

        #FONTS
        self.font_big = ("Ubuntu", 20, "bold")
        self.button_font = ("Ubuntu", 10, )
        self.font_header = ("Ubuntu", 12, "bold")
        self.font_normal = ("Ubuntu", 10, )
        #ttk styles
        self.style = ttk.Style()
        self.style.configure('big.TButton', font=("Ubuntu", 10, "bold"))
        self.style.configure('bold.TRadiobutton', font=("Ubuntu", 10, "bold"))

        self.pack_frames()
        self.start_plotter()
        self.start_bottom_frame()
        self.start_left_frame()
        

    def pack_frames(self):
        self.left_frame = ttk.Frame(self.root, relief="sunken", padding=(5,10), width = 220)
        self.left_frame.pack(expand=False, fill = tk.Y, side = tk.LEFT)
        self.bottom_frame = Frame(self.root)
        #self.bottom_frame.pack(expand=False, fill = tk.X, side = tk.BOTTOM )
        self.plotter = Plotter(self.root)
        self.plotter.canvas.get_tk_widget().pack(expand=True, fill=tk.BOTH)

    def start_plotter(self):
        self.root.wm_title("PlainDAQ GUI v0.1")
        self.plotter.start_anim(1) 

    def start_bottom_frame(self):
        self.PlainDAQ_label = ttk.Label(self.bottom_frame, text = "bottom frame", justify = tk.CENTER)
        self.PlainDAQ_label.pack()
        self.dummy_button = ttk.Button(self.bottom_frame, text = "dummy")
        self.dummy_button.pack()


    def start_left_frame(self):

        #Kuncu teknoloji logo
        _image_label = Image.open("icons/kuncu_maker.png")
        _image_label = _image_label.resize((120,110),Image.ANTIALIAS)
        self.img_logo = ImageTk.PhotoImage(_image_label)    
        self.logo_label = tk.Label(self.left_frame,height = 150, image = self.img_logo)
        self.logo_label.pack(expand = False, side = tk.TOP)

        #Input Channels FrameLabel
        self.channel_ON_OFF_frame_text = ttk.Label(self.left_frame, text="Channels:", font=self.font_header)
        self.channel_ON_OFF_frame = ttk.LabelFrame(self.left_frame, labelwidget=self.channel_ON_OFF_frame_text ,
        width = 150, height = 50, padding = 10)
        
        #Channel ON/OFF buttons
        self.CH1_button_var = tk.IntVar()
        self.CH2_button_var = tk.IntVar()
        self.CH3_button_var = tk.IntVar()
        self.CH4_button_var = tk.IntVar()
        self.CH1_button = ttk.Checkbutton(self.channel_ON_OFF_frame ,text = "CH1",
        width = 4, variable=self.CH1_button_var, onvalue = 1, offvalue = 0)
        self.CH1_button.grid(column=0, row=0, padx=0,ipadx = 0)
        self.CH2_button = ttk.Checkbutton(self.channel_ON_OFF_frame ,text = "CH2",
        width = 4, variable=self.CH2_button_var, onvalue = 1, offvalue = 0)
        self.CH2_button.grid(column=0, row=1, padx=0)
        self.CH3_button = ttk.Checkbutton(self.channel_ON_OFF_frame ,text = "CH3",
        width = 4, variable=self.CH3_button_var, onvalue = 1, offvalue = 0)
        self.CH3_button.grid(column=0, row=2, padx=0)
        self.CH4_button = ttk.Checkbutton(self.channel_ON_OFF_frame ,text = "CH4",
        width = 4, variable=self.CH4_button_var, onvalue = 1, offvalue = 0)
        self.CH4_button.grid(column=0, row=3, padx=0)


        #number of samples Frame Label
        self.numsample_label = ttk.Label(self.left_frame, text="Num. Samples:", font=self.font_header)
        self.numsample_label_frame = ttk.LabelFrame(self.left_frame, labelwidget=self.numsample_label,
        width = 150, height = 50, padding = 10)
        
        #number of samples combobox
        self.numsample_combobox = ttk.Combobox(self.numsample_label_frame, values = ["1000","2000"], width=19)
        self.numsample_combobox.pack()

        #Range select FrameLabel
        self.range_select_frame_text = ttk.Label(self.left_frame, text="Range: ", font=self.font_header)
        self.range_select_frame = ttk.LabelFrame(self.left_frame, labelwidget=self.range_select_frame_text ,
        width = 150, height = 50, padding = 10)
        
        ##RadioButton for range selection
        self.range_sel_radio_var = tk.IntVar()
        self.range_sel_RadioButton_0V5 = ttk.Radiobutton(self.range_select_frame, text = u"\u00B1" + "0.5V",
        style="bold.TRadiobutton", variable=self.range_sel_radio_var, value = 0.5, compound=tk.BOTTOM)
        self.range_sel_RadioButton_0V5.grid(column=0, row=0)
        self.range_sel_RadioButton_1V = ttk.Radiobutton(self.range_select_frame, text = u"\u00B1" + "1V   ",
        style="bold.TRadiobutton", variable=self.range_sel_radio_var, value = 1, compound=tk.BOTTOM)
        self.range_sel_RadioButton_1V.grid(column=0, row=1)
        self.range_sel_RadioButton_2V = ttk.Radiobutton(self.range_select_frame, text = u"\u00B1" + "2V   ",
        style="bold.TRadiobutton", variable=self.range_sel_radio_var, value = 2, compound=tk.BOTTOM)
        self.range_sel_RadioButton_2V.grid(column=0, row=2)
        self.range_sel_RadioButton_4V = ttk.Radiobutton(self.range_select_frame, text = u"\u00B1" + "4V   ",
        style="bold.TRadiobutton", variable=self.range_sel_radio_var, value = 4, compound=tk.BOTTOM)
        self.range_sel_RadioButton_4V.grid(column=0, row=3)
        self.range_sel_RadioButton_0V5.invoke() #pick 0.5V range as default

        #Y-Scale notebook
        self.y_scale_notebook = ttk.Notebook(self.left_frame)
        self.y_scale_CH1_y_scale = ttk.Frame(self.y_scale_notebook, width=150, height=100)
        self.y_scale_CH1_y_scale.pack(fill="both", expand=True)
        self.y_scale_CH2_y_scale = ttk.Frame(self.y_scale_notebook)
        self.y_scale_CH2_y_scale.pack(fill="both", expand=True)
        self.y_scale_CH3_y_scale = ttk.Frame(self.y_scale_notebook)
        self.y_scale_CH3_y_scale.pack(fill="both", expand=True)
        self.y_scale_CH4_y_scale = ttk.Frame(self.y_scale_notebook)
        self.y_scale_CH4_y_scale.pack(fill="both", expand=True)

        self.y_scale_notebook.add(self.y_scale_CH1_y_scale, text="CH1")
        self.y_scale_notebook.add(self.y_scale_CH2_y_scale, text="CH2")
        self.y_scale_notebook.add(self.y_scale_CH3_y_scale, text="CH3")
        self.y_scale_notebook.add(self.y_scale_CH4_y_scale, text="CH4")
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

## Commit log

2022-01-24 Create schematic_pdf
2022-03-19 sinewave_stress_test.py
    Before I start developing GUI for PlainDAQ, I wanted to see how far I can push it.
    In this stress test I tried to use matplotlib's animation functionality, and pushed it to its limit.
    The interval of the animation is set 1ms to make it update the display as fast as possible. In each frame a 2000 sample long sinewave with different frequency, amplitude and phase is generated for th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
    It can achieve about 60FPS in my computer which more than I need.
2022-03-19 Create sinewave_stress_test.py
    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
2022-06-05 Create DAC_reconstruction
    DAC reconstruction filter simulation and comparison
2022-06-05 Create DAC_reconstruction.asc
    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
2022-08-24 Delete schematic_pdf directory
    Deleted because it's an outdated version of PlainDAQ
2023-04-03 Type fixes in plaindaq_GUI
    [controller.py]
